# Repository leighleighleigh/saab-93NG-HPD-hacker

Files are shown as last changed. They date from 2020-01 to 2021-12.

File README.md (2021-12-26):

# saab-93NG-HPD-hacker
A reverse-engineering and interfacing board for the Saab Information Display / High Position Display, on 2003-2006 9-3 (Second Generation) Models.

<p align="center">
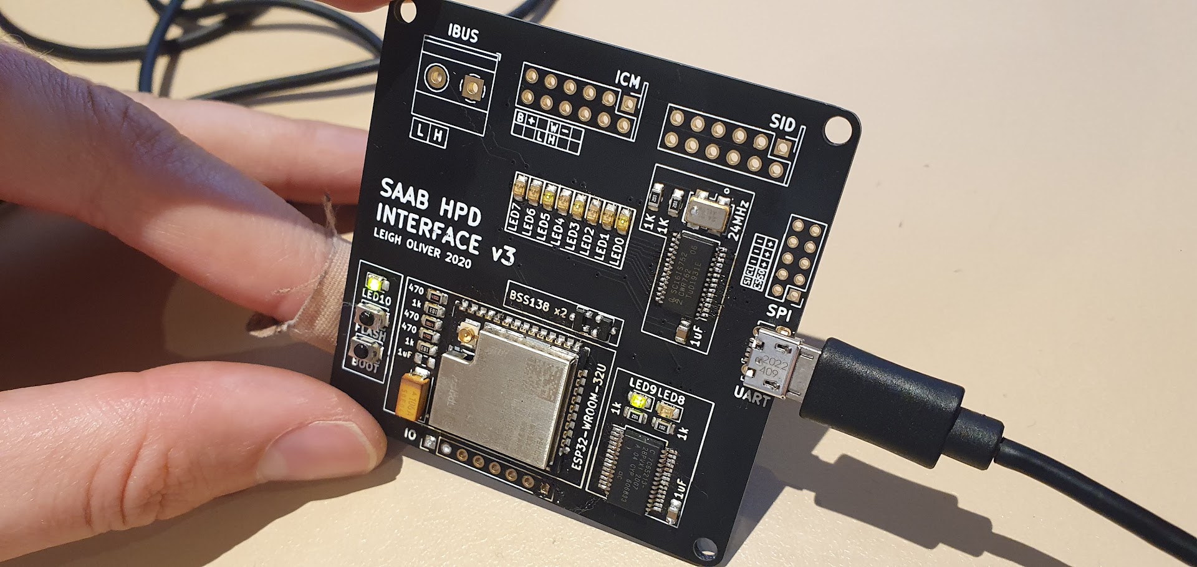
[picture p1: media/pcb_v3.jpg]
A square black circuit board with white text marked 'SAAB HPD INTERFACE v3' rests on a cream coloured benchtop.

</p>

## Project Status (DEC **2021**)
The **third** prototype of the PCB has been assembled and tested, as of August **2020**.
During this testing period, mild success was had, and some text/images were displayed. The full protocol is yet to be determined.
<p align="center">
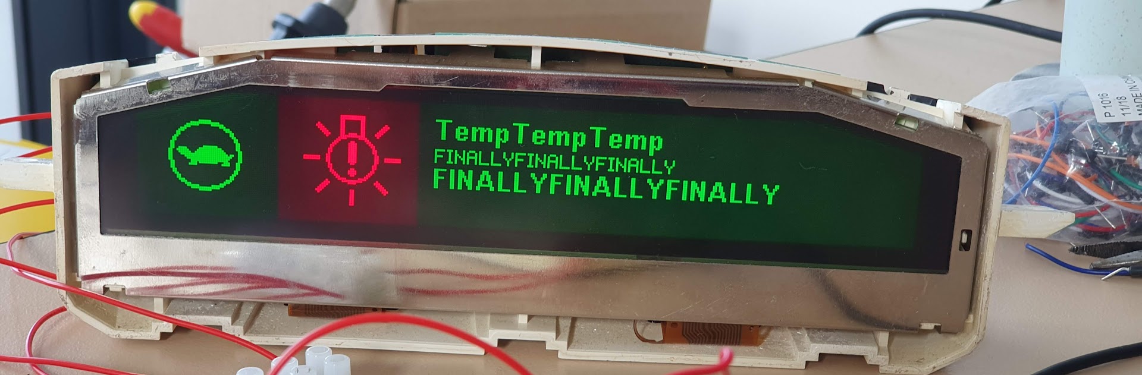
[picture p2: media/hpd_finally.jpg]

</p>

## Protocol Reverse Engineering
Please see [UART PROTOCOL](/UART_PROTOCOL.md) 

## Hardware Diagram
### Full In-car System
<p align="center">
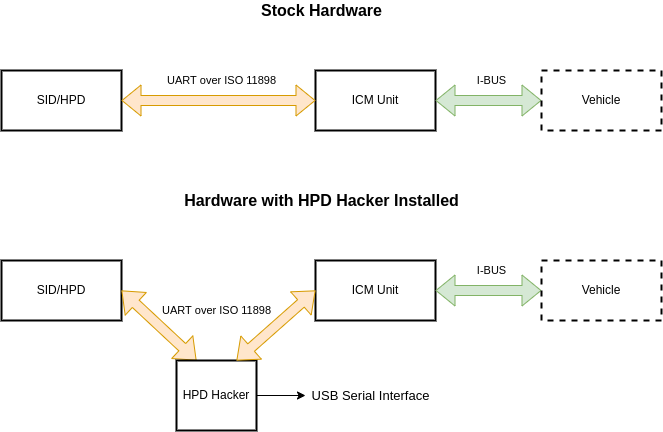
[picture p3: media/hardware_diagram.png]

</p>

### HPD Interface v3 Internals (WIP)
The HPD hacker is unusual in that it utilises a dedicated UART interface accesible over SPI.
This eliminates the need for dedicated UART interfaces on the host microcontroller, which was a concern when the original design targeted the ESP8266.
The ESP32 series has enough hardware UARTs to do this on it's own, which will be utilised in the next hardware revision.
<p align="center">
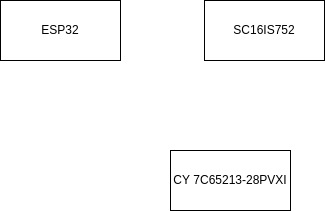
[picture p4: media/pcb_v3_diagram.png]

</p>

## Project structure
```bash
├── data_dumps # Raw UART data, CSV files exported from 'KingstVIS' software
├── hardware # KICAD v5+ projects
├── media # Images and diagrams
├── software # PlatformIO projects for the microcontrollers used here
└── PROTOCOL.md # This is where the results of our efforts is stored
```

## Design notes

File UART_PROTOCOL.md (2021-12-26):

# SID HPD Protocol
This document is incomplete.

Thanks to users **ruthenianboy** and **bojer** of trionictuning.com for their work in reverse-engineering the protocol of the SID.

## Physical Interface

- **115200baud** UART over CAN physical layer.

## Communication sequence

1. ICM sends command to SID
2. SID replies with ACK/ERROR or other frame. 
3. SID ALWAYS replies.

## Frame format

| 0x4 | 0x70 | 0x0  | 0x2 | 0x0 | 0x0 |
| --- | --- | ---- | --- | --- | --- |
| DLC(1) | COMMAND(1) | 0x0  | DATA(DLC-2)[0] | DATA(DLC-2)[1] | CHECKSUM(1) |

CHECKSUM is the MSB of all the non-DLC bytes.

## Commands table

| COMMAND BYTE | DATA BYTES DESCRIPTIONS | RESPONSE | DESCRIPTION |
| --- | --- | --- | --- |
| 0x80 | b0: Green LED brightness<br />b1: Orange/RED LED brightness  | OK | Adjusts backlight. |
| 0x81 | | 0x82...  | Status? |
| 0x83 | | 0x84...  | Status? |
| 0x10 | [0]: Region ID<br/>[2:3]: Sub-region ID <br/>[4]: ??? Usually 0x0<br/><br />[5]: Font Style<br />[6]: Width<br/>[8]: X Position<br/>[10]: Y Position<br/>[11+]: Text data | OK | Setup layer on region, with text data. |
| 0x11 | [0]: Region ID<br/>[2:3]: Sub Region ID<br/>[4]: ????, 0x8 for normal, sometimes 0x2<br/>[5]: Style<br/> # 0x00, normal<br/> # 0x10, right aligned<br/> # 0x20, blinking<br/> # 0x40, inverted <br/> # 0x80, underline<br /> | OK | Adjust layer presentation. |
| 0x60 | [0]: Region ID<br />[2]: Clear Flag (0x0) | OK | CLEAR region. |
| 0x70 | [0]: Region ID<br />[2]: Draw Flag (0 or 1) | OK | DRAW region. |
| 0x30 | # [0]: Region ID<br/># [2:3]: Sub-region ID<br/># [4]: Icon Number<br/># [5]: Icon Style<br/># [6]: X Pos<br/># [7]: Right Align | | Setup ICON |
| 0x33 | usual region stuff. 4,5 are car door state. 6 is x pos like icon. 7 must be 0 else no works. | | Draw CAR door stats |
| 0x40 | | | Some kind of raw display stuff, does weird things. |
| 0xa0 | | | Not sure? |
| 0x20 | | | Related to creating groups of sub-regions. |
| 0x21 | | | Related to moving groups of sub-regions. |
| | | | |

- 0x80,0x80 clear screen / screen off
- 0x80,0x00,0xCE,0x00 (sets backlight for orange portion, last value is brightness)
      0xC, shows only the orange portion.

- 0x80,0x00-x79 screen on, brightess command?
- 0x81,0x00 (gets info from SID, status query?)
- 0x83,0x00 (gets some kind of info from SID, status query?)
- 0x11 < draw data to screen

- 0x70,0x0,0x76,0x0,0x01 < Displays brake light failure icon

- 0x94, some kind of serial code
- 0x96, some other kind of serial code

- 0x9f,0x00 < self test mode

Return values

- 0xff,0x00 (success)
- 0xfe,0x00,0x31 (invalid commmand / command doesn't exist)
- 0xfe,0x00,0x34 (invalid command length, arguments?)
- 0xfe,0x00,0x35 ( no idea)
- 0xfe,0x0,0x37 (no idea)

## MISC

- Panel resolution (green) is 384x64 px
- Icon resolution (orange) is 64x64 px
- Temp and light sensors
- 4 font sizes, underscore, solid background, flashing, and align right styles.

## ICON DATA CODES (DECIMAL):

- dec	desc		
- 65	!		
- 66	washer 	?	
- 67	wipers !		
- 68	CRUISE		
- 69	BREAK Park		
- 70	BREAK !		
- 71	BREAK ABS		
- 72	BATTERY		
- 73	COOLANT		
- 74	OIL temp		
- 75	OIL		
- 76	OIL level		
- 77	ENGINE		
- 78	CAR		
- 79	DOOR FL		
- 80	DOOR RL		
- 81	DOOR FR		
- 82	DOOR RR		
- 83	BOOT		
- 84	LIGHT		
- 85	AHL !		
- 86	GEARBOX !		
- 87	GEARBOX temp		
- 88	TURTLE	???	
- 89	SERVICE		
- 90	PASS		
- 91	SRS		
- 92	KEY		
- 93	KEY battery		
- 94	LOCK !		
- 95	CAR LOCK !		
- 96	SEATS rear		
- 97	"P"		
- 98	SPA on	???	
- 99	SPA off	???	
- 100	SPA !		
- 101	Tire !		
- 102	Tire dot		
- 103	STP		
- 104	SEATS front		
- 105	SCL lock		
- 106	SCL !		
- 107	ESP on		
- 108	ESP off		
- 109	STP closed	???	
- 110	STP !		
- 111	STP down	???	
- 112	SNOW/ACC off	???	
- 113	Fuel lid open	???	
- 114	NAV up		arrow
- 115	NAV up right		
- 116	NAV up left		
- 117	NAV UP		filled
- 118	NAV UP RIGHT		filled
- 119	NAV UP LEFT		filled
- 120	NAV HALF SKEW RIGHT		filled
- 121	NAV HALF SKEW LEFT		filled
- 122	NAV RIGHT		filled
- 123	NAV LEFT		filled
- 124	NAV RIGHT DOWN		filled
- 125	NAV LEFT DOWN		filled
- 126	NAV RETURN right		filled
- 127	NAV RETURN left		filled
- 128	NAV DOT		
- 129-135	NAV G right		arrow filled
- 136-142	NAV G left		arrow filled
- 143-156	NAV G background		
- 157	NAV TRIANGLE UP		filled
- 158	NAV UP target		filled
- 159	NAV WAYPOINT		filled
- 160	NAV up long		
- 161	NAV skew up right		
- 162	NAV right		
- 163	NAV skew down right		
- 164	NAV down		
- 165	NAV skew down left		
- 166	NAV left		
- 167	NAV skew up left		
- 168	NAV ROTATE LEFT		filled
- 169	NAV ROTATE RIGHT		filled

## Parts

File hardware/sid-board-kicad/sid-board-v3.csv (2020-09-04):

Source: | /home/leigh/Documents/GitHub/saab-sid-re-board/sid-board-kicad/sid-board-v3.sch
Date: | Wed 02 Sep 2020 19:56:52
Tool: | Eeschema 5.1.5+dfsg1-2build2
Generator: | /usr/share/kicad/plugins/bom_csv_grouped_by_value.py
Component Count: | 49
Individual Components:
Item | Qty | Reference(s) | Value | LibPart | Footprint | Datasheet
 |  | C1 | 1uF | Device:C_Small | Capacitor_SMD:C_0805_2012Metric_Pad1.15x1.40mm_HandSolder | ~
 |  | C2 | 1uF | Device:C_Small | Capacitor_SMD:C_0805_2012Metric_Pad1.15x1.40mm_HandSolder | ~
 |  | C3 | 1uF | Device:C_Small | Capacitor_SMD:C_0805_2012Metric_Pad1.15x1.40mm_HandSolder | ~
 |  | C4 | 1uF | Device:C_Small | Capacitor_SMD:C_0805_2012Metric_Pad1.15x1.40mm_HandSolder | ~
 |  | C5 | 1uF | Device:C_Small | Capacitor_SMD:C_0805_2012Metric_Pad1.15x1.40mm_HandSolder | ~
 |  | C6 | 1uF | Device:C_Small | Capacitor_SMD:C_0805_2012Metric_Pad1.15x1.40mm_HandSolder | ~
 |  | C7 | 10uF | Device:C_Small | Capacitor_Tantalum_SMD:CP_EIA-6032-20_AVX-F_Pad2.25x2.35mm_HandSolder | ~
 |  | C8 | 1uF | Device:C_Small | Capacitor_SMD:C_0805_2012Metric_Pad1.15x1.40mm_HandSolder | ~
 |  | C9 | 1uF | Device:C_Small | Capacitor_SMD:C_0805_2012Metric_Pad1.15x1.40mm_HandSolder | ~
 |  | D1 | LED7 | Device:LED | LED_SMD:LED_0805_2012Metric_Pad1.15x1.40mm_HandSolder | ~
 |  | D2 | LED6 | Device:LED | LED_SMD:LED_0805_2012Metric_Pad1.15x1.40mm_HandSolder | ~
 |  | D3 | LED5 | Device:LED | LED_SMD:LED_0805_2012Metric_Pad1.15x1.40mm_HandSolder | ~
 |  | D4 | LED4 | Device:LED | LED_SMD:LED_0805_2012Metric_Pad1.15x1.40mm_HandSolder | ~
 |  | D5 | LED3 | Device:LED | LED_SMD:LED_0805_2012Metric_Pad1.15x1.40mm_HandSolder | ~
 |  | D6 | LED2 | Device:LED | LED_SMD:LED_0805_2012Metric_Pad1.15x1.40mm_HandSolder | ~
 |  | D7 | LED1 | Device:LED | LED_SMD:LED_0805_2012Metric_Pad1.15x1.40mm_HandSolder | ~
 |  | D8 | LED0 | Device:LED | LED_SMD:LED_0805_2012Metric_Pad1.15x1.40mm_HandSolder | ~
 |  | D9 | LED_IO2 | Device:LED_Small | LED_SMD:LED_0805_2012Metric_Pad1.15x1.40mm_HandSolder | ~
 |  | D10 | 1N5819 | Diode:1N5819 | Diode_SMD:D_SOD-123 | http://www.vishay.com/docs/88525/1n5817.pdf
 |  | D11 | 1N5819 | Diode:1N5819 | Diode_SMD:D_SOD-123 | http://www.vishay.com/docs/88525/1n5817.pdf
 |  | D12 | LED0 | Device:LED | LED_SMD:LED_0805_2012Metric_Pad1.15x1.40mm_HandSolder | ~
 |  | D13 | LED0 | Device:LED | LED_SMD:LED_0805_2012Metric_Pad1.15x1.40mm_HandSolder | ~
 |  | I-BUS1 | Screw_Terminal_01x02 | Connector:Screw_Terminal_01x02 | TerminalBlock_Phoenix:TerminalBlock_Phoenix_MKDS-1,5-2-5.08_1x02_P5.08mm_Horizontal | ~
 |  | ICM1 | ICM_CONN | local_symbols:Conn_02x06_SAAB_SID_HPD | sid-board:SAAB_SID_CONNECTOR_HEADER | ~
 |  | J1 | SPI + UART | Connector_Generic:Conn_02x05_Counter_Clockwise | Connector_PinHeader_2.00mm:PinHeader_2x05_P2.00mm_Vertical | ~
 |  | J2 | USB_B_Micro | Connector:USB_B_Micro | Connector_USB:USB_Micro-B_Molex-105017-0001 | ~
 |  | J3 | Conn_01x08 | Connector_Generic:Conn_01x08 | Connector_PinHeader_2.54mm:PinHeader_1x08_P2.54mm_Vertical | ~
 |  | Q1 | BSS138 | Transistor_FET:BSS138 | Package_TO_SOT_SMD:SOT-23 | https://www.fairchildsemi.com/datasheets/BS/BSS138.pdf
 |  | Q2 | BSS138 | Transistor_FET:BSS138 | Package_TO_SOT_SMD:SOT-23 | https://www.fairchildsemi.com/datasheets/BS/BSS138.pdf
 |  | R1 | 1K | Device:R_Small | Resistor_SMD:R_0805_2012Metric_Pad1.15x1.40mm_HandSolder | ~
 |  | R2 | 470 | Device:R_Small | Resistor_SMD:R_0805_2012Metric_Pad1.15x1.40mm_HandSolder | ~
 |  | R3 | 470 | Device:R_Small | Resistor_SMD:R_0805_2012Metric_Pad1.15x1.40mm_HandSolder | ~
 |  | R4 | 10k | Device:R_Small | Resistor_SMD:R_0805_2012Metric_Pad1.15x1.40mm_HandSolder | ~
 |  | R5 | 10k | Device:R_Small | Resistor_SMD:R_0805_2012Metric_Pad1.15x1.40mm_HandSolder | ~
 |  | R6 | 470 | Device:R_Small | Resistor_SMD:R_0805_2012Metric_Pad1.15x1.40mm_HandSolder | ~
 |  | R7 | 1k | Device:R_Small | Resistor_SMD:R_0805_2012Metric_Pad1.15x1.40mm_HandSolder | ~
 |  | R8 | 1k | Device:R_Small | Resistor_SMD:R_0805_2012Metric_Pad1.15x1.40mm_HandSolder | ~
 |  | R18 | 1K | Device:R_Small | Resistor_SMD:R_0805_2012Metric_Pad1.15x1.40mm_HandSolder | ~
 |  | SID1 | SID_CONN | local_symbols:Conn_02x06_SAAB_SID_HPD | sid-board:SAAB_SID_CONNECTOR_HEADER | ~
 |  | SW1 | SW_EN | Switch:SW_Push | Button_Switch_SMD:SW_Push_SPST_NO_Alps_SKRK | ~
 |  | SW2 | SW_FLASH | Switch:SW_Push | Button_Switch_SMD:SW_Push_SPST_NO_Alps_SKRK | ~
 |  | U1 | SC16IS752IPW | local_symbols:SC16IS752IPW_SPI | Package_SO:TSSOP-28_4.4x9.7mm_P0.65mm | https://au.mouser.com/datasheet/2/302/SC16IS752_SC16IS762-1127856.pdf
 |  | U2 | MCP1703A-3302_SOT223 | Regulator_Linear:MCP1703A-3302_SOT223 | Package_TO_SOT_SMD:SOT-223-3_TabPin2 | http://ww1.microchip.com/downloads/en/DeviceDoc/20005122B.pdf
 |  | U3 | SN65HVD232 | Interface_CAN_LIN:SN65HVD232 | Package_SO:SOIC-8_3.9x4.9mm_P1.27mm | http://www.ti.com/lit/ds/symlink/sn65hvd230.pdf
 |  | U4 | SN65HVD232 | Interface_CAN_LIN:SN65HVD232 | Package_SO:SOIC-8_3.9x4.9mm_P1.27mm | http://www.ti.com/lit/ds/symlink/sn65hvd230.pdf
 |  | U5 | CY7C65213-28PVXI | Interface_USB:CY7C65213-28PVXI | Package_SO:SSOP-28_5.3x10.2mm_P0.65mm | http://www.cypress.com/file/139881/download
 |  | U6 | ESP32-WROOM-32U | RF_Module:ESP32-WROOM-32U | RF_Module:ESP32-WROOM-32U | https://www.espressif.com/sites/default/files/documentation/esp32-wroom-32d_esp32-wroom-32u_datasheet_en.pdf
 |  | U7 | SN65HVD232 | Interface_CAN_LIN:SN65HVD232 | Package_SO:SOIC-8_3.9x4.9mm_P1.27mm | http://www.ti.com/lit/ds/symlink/sn65hvd230.pdf
 |  | X1 | ASE-xxxMHz | Oscillator:ASE-xxxMHz | Oscillator:Oscillator_SMD_EuroQuartz_XO53-4Pin_5.0x3.2mm_HandSoldering | http://www.abracon.com/Oscillators/ASV.pdf
Collated Components:
Item | Qty | Reference(s) | Value | LibPart | Footprint | Datasheet
1 | 8 | C1, C2, C3, C4, C5, C6, C8, C9 | 1uF | Device:C_Small | Capacitor_SMD:C_0805_2012Metric_Pad1.15x1.40mm_HandSolder | ~
2 | 1 | C7 | 10uF | Device:C_Small | Capacitor_Tantalum_SMD:CP_EIA-6032-20_AVX-F_Pad2.25x2.35mm_HandSolder | ~
3 | 1 | D1 | LED7 | Device:LED | LED_SMD:LED_0805_2012Metric_Pad1.15x1.40mm_HandSolder | ~
4 | 1 | D2 | LED6 | Device:LED | LED_SMD:LED_0805_2012Metric_Pad1.15x1.40mm_HandSolder | ~
5 | 1 | D3 | LED5 | Device:LED | LED_SMD:LED_0805_2012Metric_Pad1.15x1.40mm_HandSolder | ~
6 | 1 | D4 | LED4 | Device:LED | LED_SMD:LED_0805_2012Metric_Pad1.15x1.40mm_HandSolder | ~
7 | 1 | D5 | LED3 | Device:LED | LED_SMD:LED_0805_2012Metric_Pad1.15x1.40mm_HandSolder | ~
8 | 1 | D6 | LED2 | Device:LED | LED_SMD:LED_0805_2012Metric_Pad1.15x1.40mm_HandSolder | ~
9 | 1 | D7 | LED1 | Device:LED | LED_SMD:LED_0805_2012Metric_Pad1.15x1.40mm_HandSolder | ~
10 | 3 | D8, D12, D13 | LED0 | Device:LED | LED_SMD:LED_0805_2012Metric_Pad1.15x1.40mm_HandSolder | ~
11 | 1 | D9 | LED_IO2 | Device:LED_Small | LED_SMD:LED_0805_2012Metric_Pad1.15x1.40mm_HandSolder | ~
12 | 2 | D10, D11 | 1N5819 | Diode:1N5819 | Diode_SMD:D_SOD-123 | http://www.vishay.com/docs/88525/1n5817.pdf
13 | 1 | I-BUS1 | Screw_Terminal_01x02 | Connector:Screw_Terminal_01x02 | TerminalBlock_Phoenix:TerminalBlock_Phoenix_MKDS-1,5-2-5.08_1x02_P5.08mm_Horizontal | ~
14 | 1 | ICM1 | ICM_CONN | local_symbols:Conn_02x06_SAAB_SID_HPD | sid-board:SAAB_SID_CONNECTOR_HEADER | ~
15 | 1 | J1 | SPI + UART | Connector_Generic:Conn_02x05_Counter_Clockwise | Connector_PinHeader_2.00mm:PinHeader_2x05_P2.00mm_Vertical | ~
16 | 1 | J2 | USB_B_Micro | Connector:USB_B_Micro | Connector_USB:USB_Micro-B_Molex-105017-0001 | ~
17 | 1 | J3 | Conn_01x08 | Connector_Generic:Conn_01x08 | Connector_PinHeader_2.54mm:PinHeader_1x08_P2.54mm_Vertical | ~
18 | 2 | Q1, Q2 | BSS138 | Transistor_FET:BSS138 | Package_TO_SOT_SMD:SOT-23 | https://www.fairchildsemi.com/datasheets/BS/BSS138.pdf
19 | 2 | R1, R18 | 1K | Device:R_Small | Resistor_SMD:R_0805_2012Metric_Pad1.15x1.40mm_HandSolder | ~
20 | 3 | R2, R3, R6 | 470 | Device:R_Small | Resistor_SMD:R_0805_2012Metric_Pad1.15x1.40mm_HandSolder | ~
21 | 2 | R4, R5 | 10k | Device:R_Small | Resistor_SMD:R_0805_2012Metric_Pad1.15x1.40mm_HandSolder | ~
22 | 2 | R7, R8 | 1k | Device:R_Small | Resistor_SMD:R_0805_2012Metric_Pad1.15x1.40mm_HandSolder | ~
23 | 1 | SID1 | SID_CONN | local_symbols:Conn_02x06_SAAB_SID_HPD | sid-board:SAAB_SID_CONNECTOR_HEADER | ~
24 | 1 | SW1 | SW_EN | Switch:SW_Push | Button_Switch_SMD:SW_Push_SPST_NO_Alps_SKRK | ~
25 | 1 | SW2 | SW_FLASH | Switch:SW_Push | Button_Switch_SMD:SW_Push_SPST_NO_Alps_SKRK | ~
26 | 1 | U1 | SC16IS752IPW | local_symbols:SC16IS752IPW_SPI | Package_SO:TSSOP-28_4.4x9.7mm_P0.65mm | https://au.mouser.com/datasheet/2/302/SC16IS752_SC16IS762-1127856.pdf
27 | 1 | U2 | MCP1703A-3302_SOT223 | Regulator_Linear:MCP1703A-3302_SOT223 | Package_TO_SOT_SMD:SOT-223-3_TabPin2 | http://ww1.microchip.com/downloads/en/DeviceDoc/20005122B.pdf
28 | 3 | U3, U4, U7 | SN65HVD232 | Interface_CAN_LIN:SN65HVD232 | Package_SO:SOIC-8_3.9x4.9mm_P1.27mm | http://www.ti.com/lit/ds/symlink/sn65hvd230.pdf
29 | 1 | U5 | CY7C65213-28PVXI | Interface_USB:CY7C65213-28PVXI | Package_SO:SSOP-28_5.3x10.2mm_P0.65mm | http://www.cypress.com/file/139881/download
30 | 1 | U6 | ESP32-WROOM-32U | RF_Module:ESP32-WROOM-32U | RF_Module:ESP32-WROOM-32U | https://www.espressif.com/sites/default/files/documentation/esp32-wroom-32d_esp32-wroom-32u_datasheet_en.pdf
31 | 1 | X1 | ASE-xxxMHz | Oscillator:ASE-xxxMHz | Oscillator:Oscillator_SMD_EuroQuartz_XO53-4Pin_5.0x3.2mm_HandSoldering | http://www.abracon.com/Oscillators/ASV.pdf

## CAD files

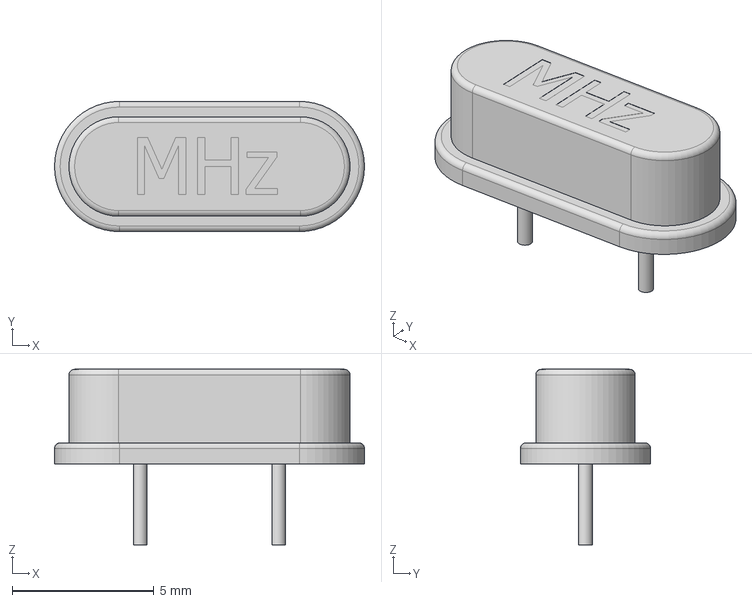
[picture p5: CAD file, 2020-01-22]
hardware/sid-board-kicad/local_libraries/3dmodels/Crystal Oscillator.stp
11.0 x 4.60 x 6.20 mm

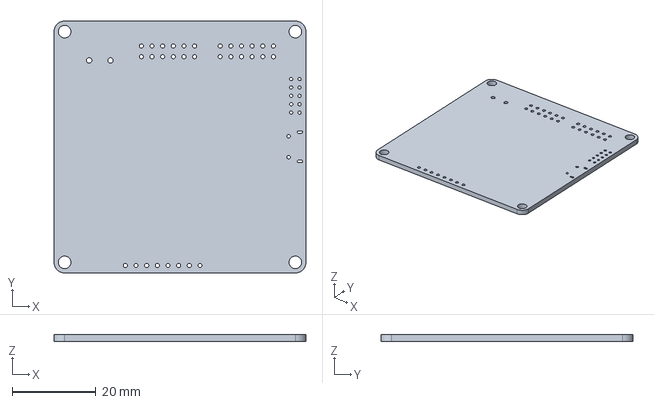
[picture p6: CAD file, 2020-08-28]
hardware/sid-board-kicad/sid-board-v3.step
60.1 x 60.1 x 1.60 mm

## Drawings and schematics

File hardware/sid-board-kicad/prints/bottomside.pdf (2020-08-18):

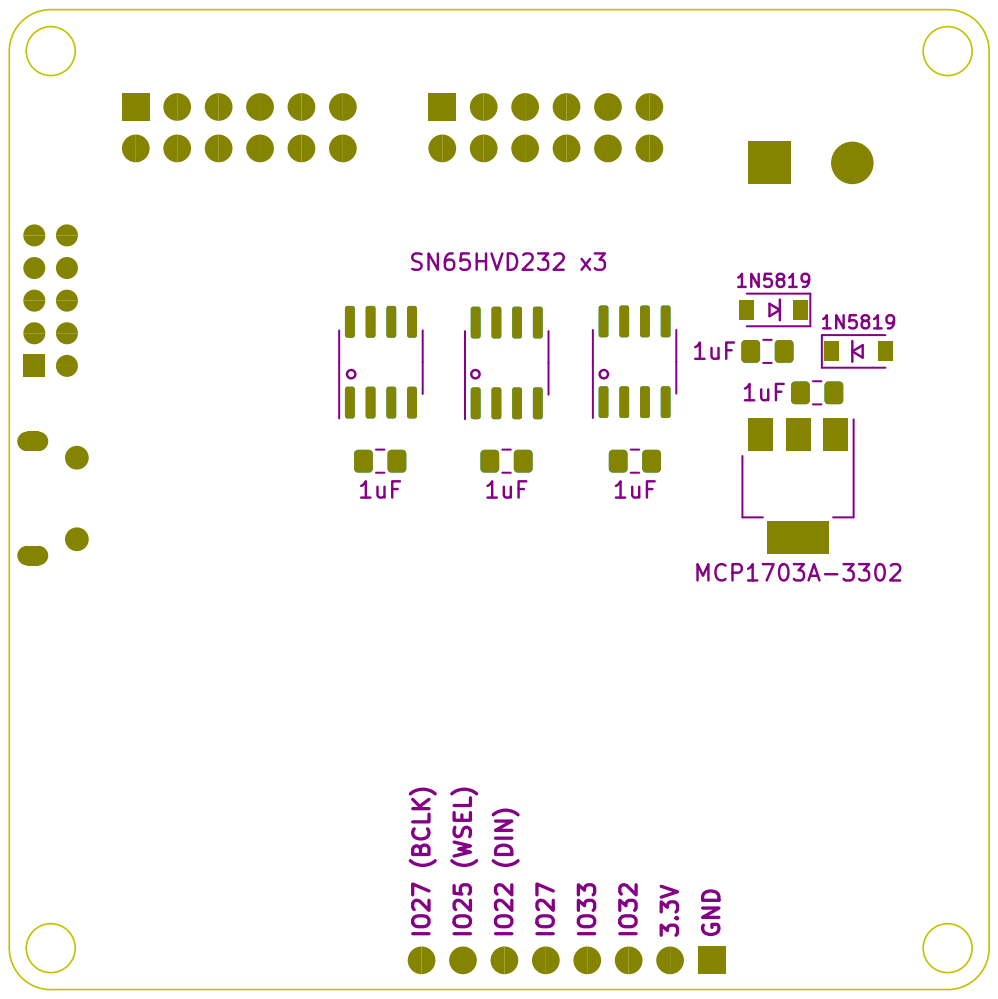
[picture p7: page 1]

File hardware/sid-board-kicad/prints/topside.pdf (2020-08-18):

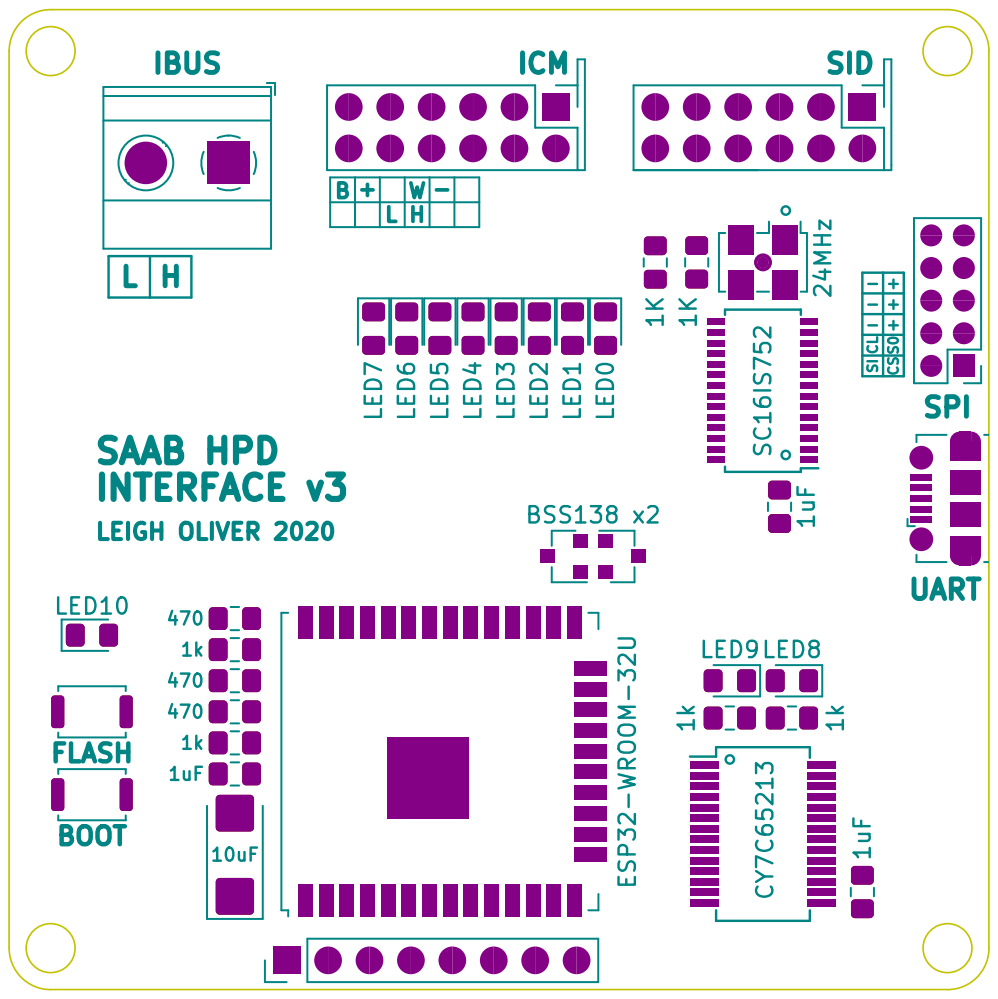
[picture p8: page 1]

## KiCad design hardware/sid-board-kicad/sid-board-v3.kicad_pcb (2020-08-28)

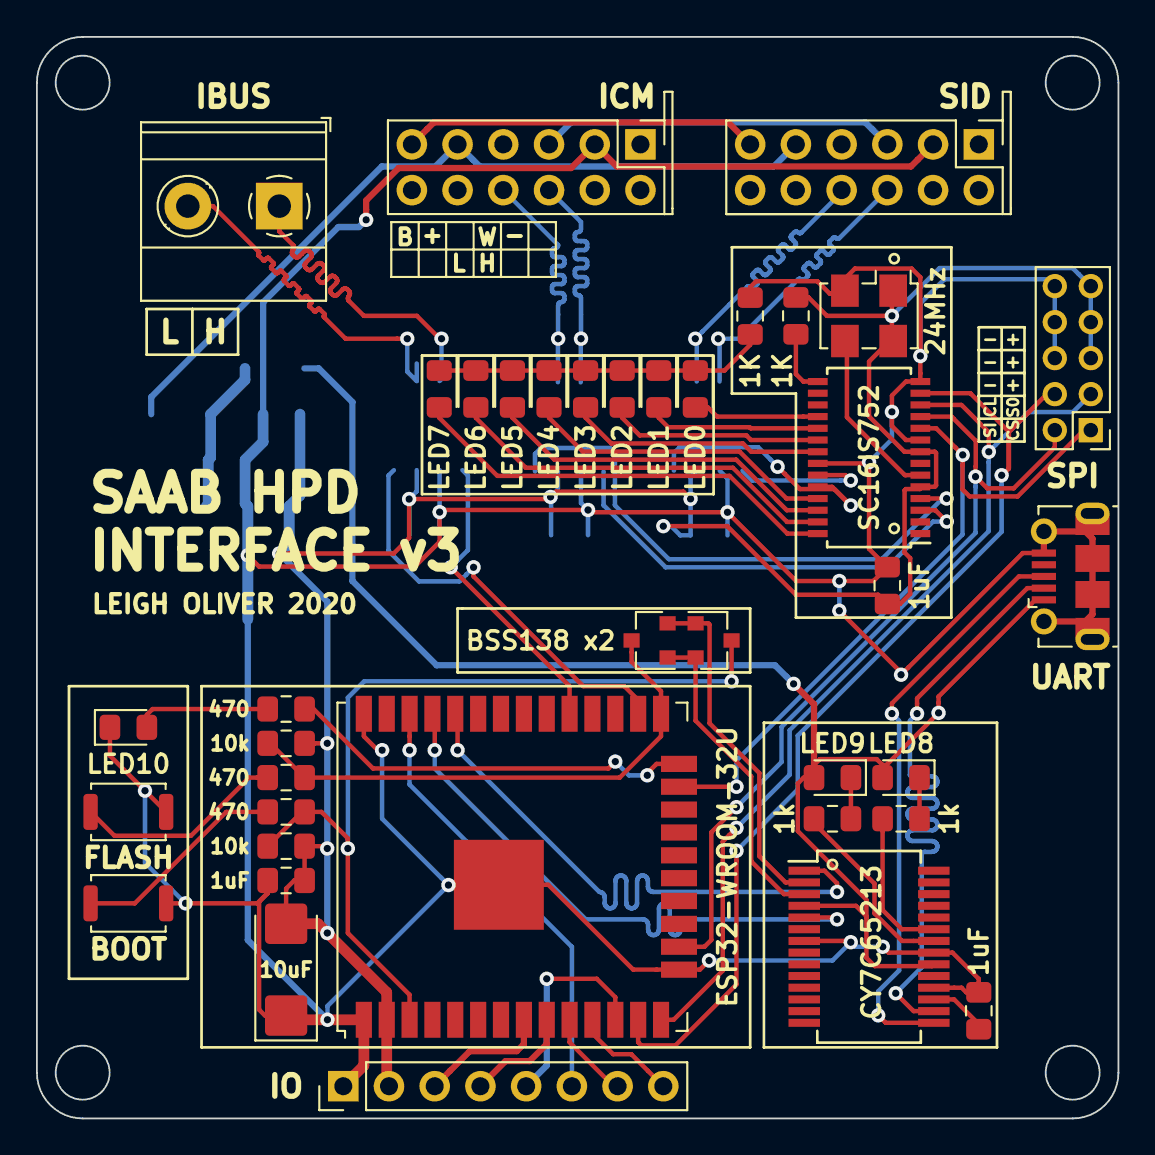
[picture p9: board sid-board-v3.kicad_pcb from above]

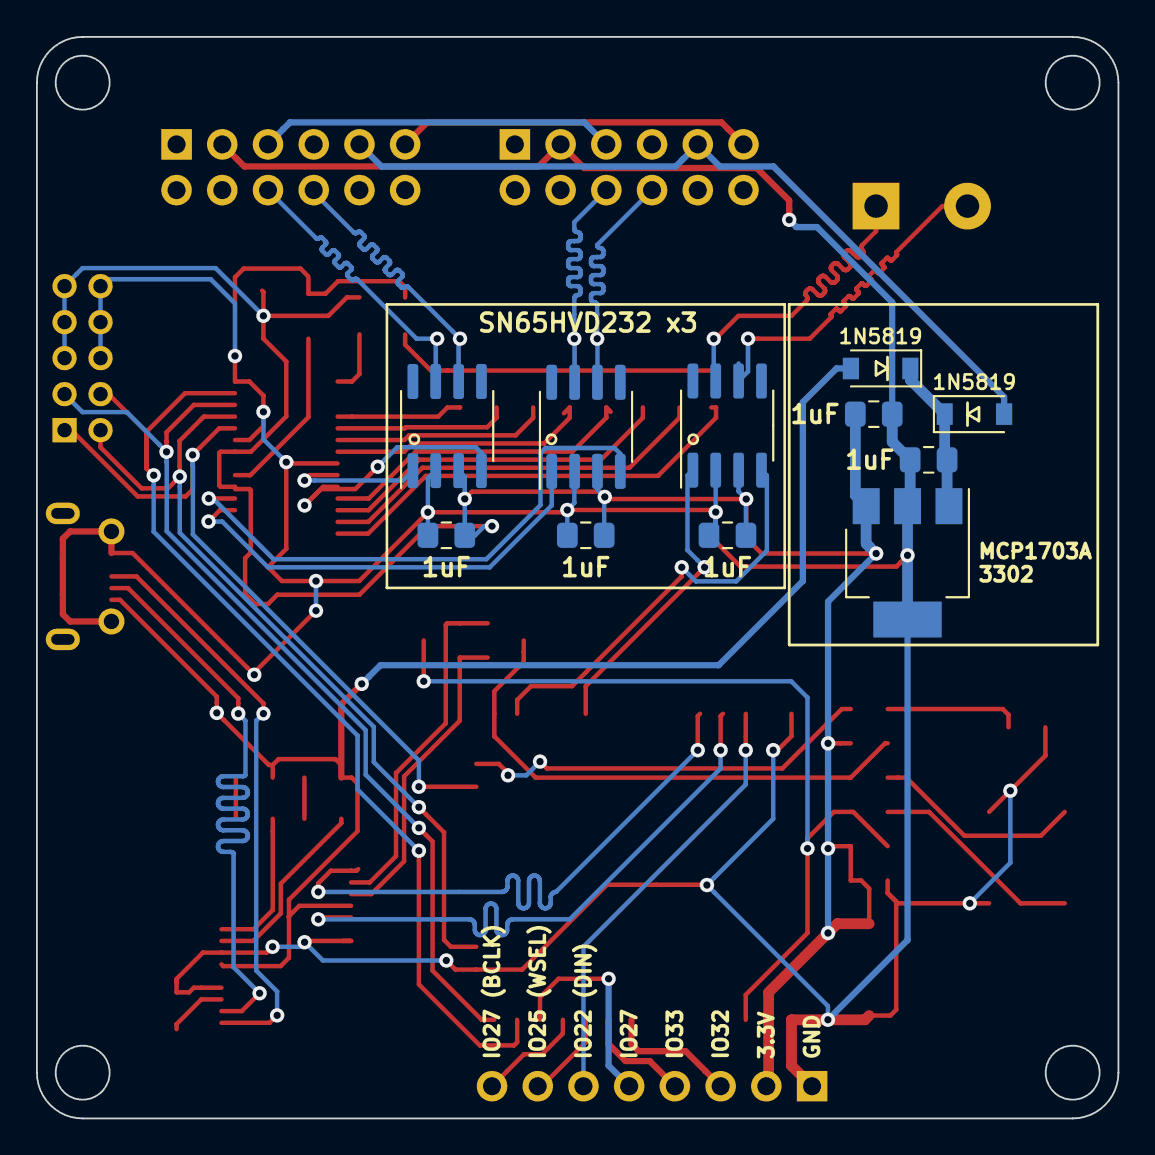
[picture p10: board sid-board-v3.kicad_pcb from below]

Board: 2 copper layers, 60.1 x 60.1 mm, 49 parts (11 on the bottom side), 57 nets.

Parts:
BSS138: BSS138 x2; SOT-23
C1, C2, C4, C5, C6, C8, C8#2, C9: 1uF; C_0805_2012Metric_Pad1.15x1.40mm_HandSolder
C7: 10uF; CP_EIA-6032-20_AVX-F_Pad2.25x2.35mm_HandSolder
D1: LED7; LED_0805_2012Metric_Pad1.15x1.40mm_HandSolder
D2: LED6; LED_0805_2012Metric_Pad1.15x1.40mm_HandSolder
D3: LED5; LED_0805_2012Metric_Pad1.15x1.40mm_HandSolder
D4: LED4; LED_0805_2012Metric_Pad1.15x1.40mm_HandSolder
D5: LED3; LED_0805_2012Metric_Pad1.15x1.40mm_HandSolder
D6: LED2; LED_0805_2012Metric_Pad1.15x1.40mm_HandSolder
D7: LED1; LED_0805_2012Metric_Pad1.15x1.40mm_HandSolder
D8: LED0; LED_0805_2012Metric_Pad1.15x1.40mm_HandSolder
D9: LED10; LED_0805_2012Metric_Pad1.15x1.40mm_HandSolder
D10, D11: 1N5819; D_SOD-123
D12: LED9; LED_0805_2012Metric_Pad1.15x1.40mm_HandSolder
D13: LED8; LED_0805_2012Metric_Pad1.15x1.40mm_HandSolder
I-BUS1: Screw_Terminal_01x02; TerminalBlock_Phoenix_MKDS-1,5-2-5.08_1x02_P5.08mm_Horizont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
ICM1: ICM_CONN; SAAB_SID_CONNECTOR_HEADER
J1: SPI; PinHeader_2x05_P2.00mm_Vertical
J2: UART; USB_Micro-B_Molex-105017-0001
J3: Conn_01x08; PinHeader_1x08_P2.54mm_Vertical
Q1: BSS138; SOT-23
R1, R18: 1K; R_0805_2012Metric_Pad1.15x1.40mm_HandSolder
R2, R3, R6: 470; R_0805_2012Metric_Pad1.15x1.40mm_HandSolder
R4, R5: 10k; R_0805_2012Metric_Pad1.15x1.40mm_HandSolder
R7, R8: 1k; R_0805_2012Metric_Pad1.15x1.40mm_HandSolder
SID1: SID_CONN; SAAB_SID_CONNECTOR_HEADER
SW1: BOOT; SW_Push_SPST_NO_Alps_SKRK
SW2: FLASH; SW_Push_SPST_NO_Alps_SKRK
U1: SC16IS752; TSSOP-28_4.4x9.7mm_P0.65mm
U2: MCP1703A3302; SOT-223-3_TabPin2
U3: SN65HVD232 x3; SOIC-8_3.9x4.9mm_P1.27mm
U4, U7: SN65HVD232; SOIC-8_3.9x4.9mm_P1.27mm
U5: CY7C65213; SSOP-28_5.3x10.2mm_P0.65mm
U6: ESP32-WROOM-32U
X1: 24MHz; Oscillator_SMD_EuroQuartz_XO53-4Pin_5.0x3.2mm_HandSoldering

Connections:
CAN_A_H: ICM1.10, U3.7
CAN_A_L: ICM1.9, U3.6
CAN_B_H: SID1.10, U4.7
CAN_B_L: SID1.9, U4.6
CAN_H: I-BUS1.1, U7.7
CAN_L: I-BUS1.2, U7.6
CLK: J1.4, U1.13, U6.13
CS: J1.1, U1.10, U6.23
DTR: BSS138.1, Q1.2, U5.2
EN: BSS138.3, R2.1, R4.2, U6.3
GND: C1.2, C2.2, C4.2, C5.2, C6.1, C7.1, C8.2, C8#2.2, C9.2, D9.1, ICM1.2, J1.6, J1.8, J1.10, J2.5, J2.6, J3.1, R18.2, SID1.2, SW1.1, SW2.1, U1.9, U1.14, U1.22, U2.2, U3.2, U4.2, U5.7, U5.18, U5.21, U6.1, U6.15, U6.38, U6.39, U7.2, X1.2
I2S_BCLK: J3.8, U6.11
I2S_DIN: J3.6, U6.36
I2S_WSEL: J3.7, U6.10
IO0: Q1.3, R3.1, R5.2, U6.25
IRQ: R1.1, U1.15
MISO: J1.3, U1.12, U6.14
MOSI: J1.2, U1.11, U6.16
unnamed: C4.1, U5.17
unnamed: D1.1, D2.1, D3.1, D4.1, D5.1, D6.1, D7.1, D8.1, R18.1
unnamed: D1.2, U1.28
unnamed: D2.2, U1.27
unnamed: D3.2, U1.26
unnamed: D4.2, U1.25
unnamed: D5.2, U1.21
unnamed: D6.2, U1.20
unnamed: D7.2, U1.19
unnamed: D8.2, U1.18
unnamed: D9.2, R6.1
unnamed: D11.2, ICM1.5, SID1.5
unnamed: D12.1, R7.2
unnamed: D13.1, R8.2
unnamed: ICM1.3, SID1.3
unnamed: ICM1.6, SID1.6
unnamed: J3.3, U6.8
unnamed: J3.4, U6.9
unnamed: J3.5, U6.12
unnamed: R2.2, SW1.2
unnamed: R3.2, SW2.2
unnamed: R6.2, U6.24
unnamed: R7.1, U5.22
unnamed: R8.1, U5.23
RTS: BSS138.2, Q1.1, U5.3
RXA: U1.4, U3.4
RXB: U1.24, U4.4
RX_ESP32: U5.1, U6.34
RX_ESP32_CAN: U6.26, U7.4
TXA: U1.3, U3.1
TXB: U1.23, U4.1
TX_ESP32: U5.5, U6.35
TX_ESP32_CAN: U6.29, U7.1
USB_DM: J2.2, U5.16
USB_DP: J2.3, U5.15
VBUS: D10.2, D12.2, D13.2, J2.1, U5.4, U5.20
VDD_3.3V: C1.1, C5.1, C6.2, C7.2, C8.1, C8#2.1, C9.1, J1.5, J1.7, J1.9, J3.2, R1.2, R4.1, R5.1, U1.5, U1.8, U2.3, U3.3, U4.3, U6.2, U7.3, X1.1, X1.4
VIN: C2.1, D10.1, D11.1, U2.1
XTAL1: U1.6, X1.3

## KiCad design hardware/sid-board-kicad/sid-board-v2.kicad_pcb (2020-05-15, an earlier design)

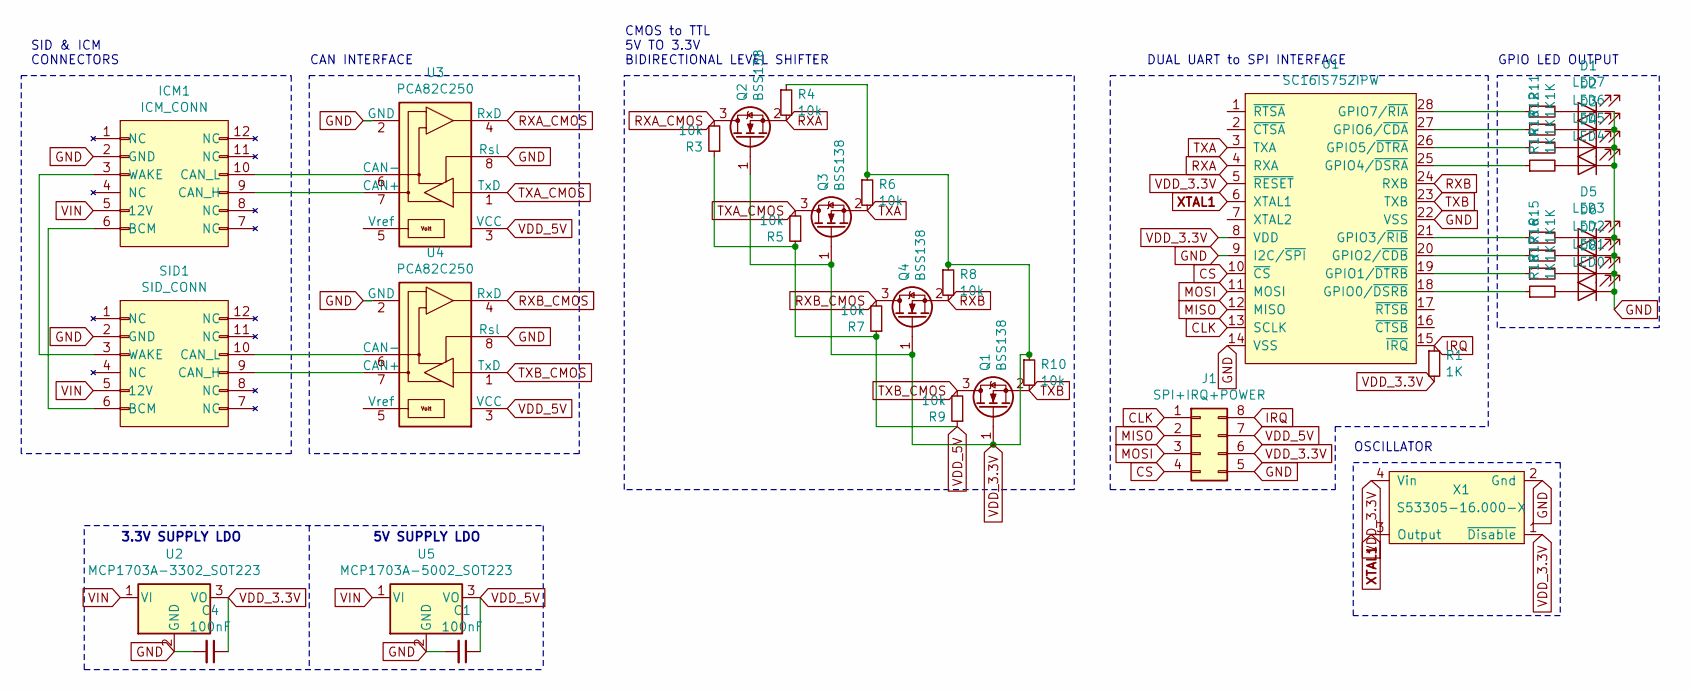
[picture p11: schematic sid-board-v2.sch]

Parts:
C1, C4: 100nF; C_0805_2012Metric_Pad1.15x1.40mm_HandSolder
D1: LED7; LED_0805_2012Metric_Pad1.15x1.40mm_HandSolder
D2: LED6; LED_0805_2012Metric_Pad1.15x1.40mm_HandSolder
D3: LED5; LED_0805_2012Metric_Pad1.15x1.40mm_HandSolder
D4: LED4; LED_0805_2012Metric_Pad1.15x1.40mm_HandSolder
D5: LED3; LED_0805_2012Metric_Pad1.15x1.40mm_HandSolder
D6: LED2; LED_0805_2012Metric_Pad1.15x1.40mm_HandSolder
D7: LED1; LED_0805_2012Metric_Pad1.15x1.40mm_HandSolder
D8: LED0; LED_0805_2012Metric_Pad1.15x1.40mm_HandSolder
ICM1: ICM_CONN; SAAB_SID_CONNECTOR_HEADER
J1: SPI+IRQ+POWER; PinSocket_2x04_P2.54mm_Vertical
Q1, Q2, Q3, Q4: BSS138; SOT-23
R1, R11, R12, R13, R14, R15, R16, R17, R18: 1K; R_0805_2012Metric_Pad1.15x1.40mm_HandSolder
R3, R4, R5, R6, R7, R8, R9, R10: 10k; R_0805_2012Metric_Pad1.15x1.40mm_HandSolder
SID1: SID_CONN; SAAB_SID_CONNECTOR_HEADER
U1: SC16IS752IPW; TSSOP-28_4.4x9.7mm_P0.65mm
U2: MCP1703A-3302_SOT223; SOT-223-3_TabPin2
U3, U4: PCA82C250; SOIC-8_3.9x4.9mm_P1.27mm
U5: MCP1703A-5002_SOT223; SOT-223-3_TabPin2
X1: S53305-16.000-X

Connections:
CLK: J1.1, U1.13 (SCLK)
CS: J1.4, U1.10 (~CS)
GND: C1.2, C4.2, D1.1 (K), D2.1 (K), D3.1 (K), D4.1 (K), D5.1 (K), D6.1 (K), D7.1 (K), D8.1 (K), ICM1.2 (GND), J1.5, SID1.2 (GND), U1.9 (I2C/~SPI), U1.14 (VSS), U1.22 (VSS), U2.2 (GND), U3.2 (GND), U3.8 (Rsl), U4.2 (GND), U4.8 (Rsl), U5.2 (GND), X1.2 (Gnd)
IRQ: J1.8, R1.1, U1.15 (~IRQ)
MISO: J1.2, U1.12 (MISO)
MOSI: J1.3, U1.11 (MOSI)
unnamed: D1.2 (A), R11.2
unnamed: D2.2 (A), R12.2
unnamed: D3.2 (A), R13.2
unnamed: D4.2 (A), R14.2
unnamed: D5.2 (A), R15.2
unnamed: D6.2 (A), R16.2
unnamed: D7.2 (A), R17.2
unnamed: D8.2 (A), R18.2
unnamed: ICM1.3 (WAKE), SID1.3 (WAKE)
unnamed: ICM1.6 (BCM), SID1.6 (BCM)
unnamed: ICM1.9 (CAN_H), U3.7 (CAN+)
unnamed: ICM1.10 (CAN_L), U3.6 (CAN-)
unnamed: R11.1, U1.28 (GPIO7/~RIA)
unnamed: R12.1, U1.27 (GPIO6/~CDA)
unnamed: R13.1, U1.26 (GPIO5/~DTRA)
unnamed: R14.1, U1.25 (GPIO4/~DSRA)
unnamed: R15.1, U1.21 (GPIO3/~RIB)
unnamed: R16.1, U1.20 (GPIO2/~CDB)
unnamed: R17.1, U1.19 (GPIO1/~DTRB)
unnamed: R18.1, U1.18 (GPIO0/~DSRB)
unnamed: SID1.9 (CAN_H), U4.7 (CAN+)
unnamed: SID1.10 (CAN_L), U4.6 (CAN-)
RXA: Q2.2 (S), R4.2, U1.4 (RXA)
RXA_CMOS: Q2.3 (D), R3.2, U3.4 (RxD)
RXB: Q4.2 (S), R8.2, U1.24 (RXB)
RXB_CMOS: Q4.3 (D), R7.2, U4.4 (RxD)
TXA: Q3.2 (S), R6.2, U1.3 (TXA)
TXA_CMOS: Q3.3 (D), R5.2, U3.1 (TxD)
TXB: Q1.2 (S), R10.2, U1.23 (TXB)
TXB_CMOS: Q1.3 (D), R9.2, U4.1 (TxD)
VDD_3.3V: C4.1, J1.6, Q1.1 (G), Q2.1 (G), Q3.1 (G), Q4.1 (G), R1.2, R4.1, R6.1, R8.1, R10.1, U1.5 (~RESET), U1.8 (VDD), U2.3 (VO), X1.1 (~Disable), X1.4 (Vin)
VDD_5V: C1.1, J1.7, R3.1, R5.1, R7.1, R9.1, U3.3 (VCC), U4.3 (VCC), U5.3 (VO)
VIN: ICM1.5 (12V), SID1.5 (12V), U2.1 (VI), U5.1 (VI)
XTAL1: U1.6 (XTAL1), X1.3 (Output)

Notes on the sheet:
3.3V SUPPLY LDO
5V SUPPLY LDO
SID & ICM CONNECTORS
CAN INTERFACE
DUAL UART to SPI INTERFACE
OSCILLATOR
CMOS to TTL 5V TO 3.3V BIDIRECTIONAL LEVEL SHIFTER
GPIO LED OUTPUT

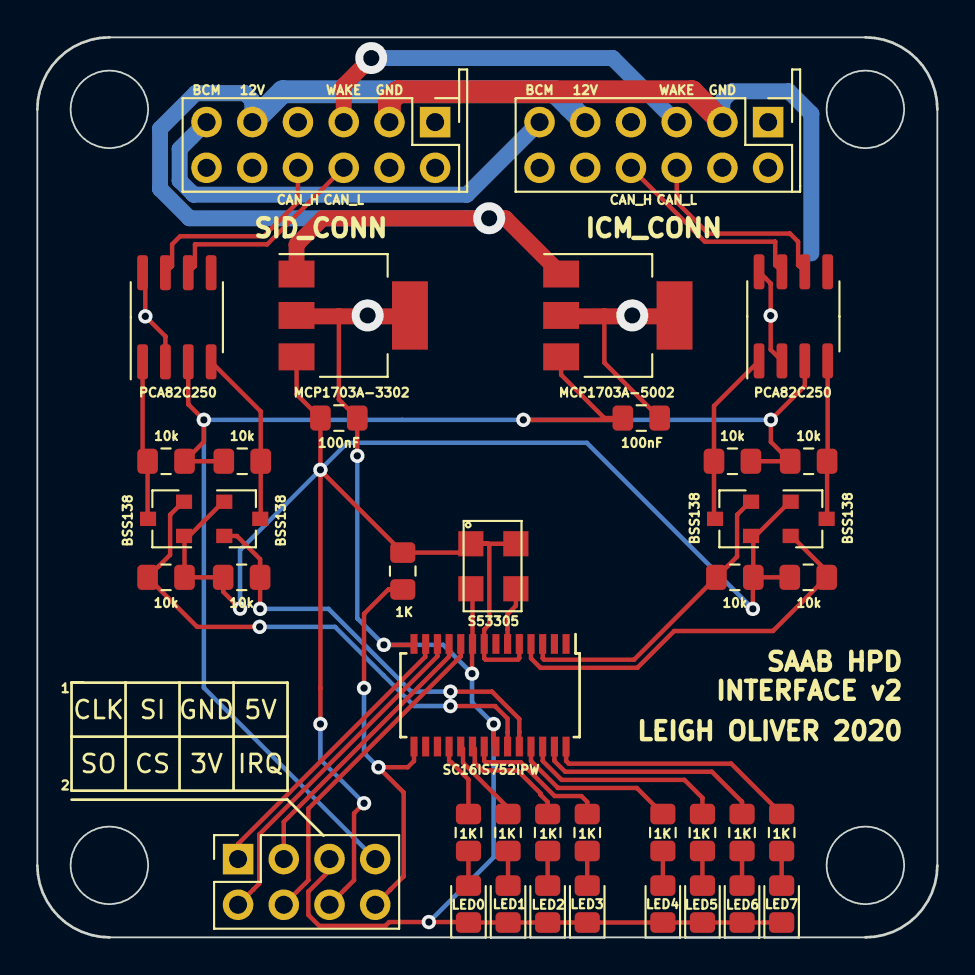
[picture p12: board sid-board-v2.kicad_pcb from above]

Board: 2 copper layers, 50.0 x 50.0 mm, 40 parts (0 on the bottom side), 40 nets.

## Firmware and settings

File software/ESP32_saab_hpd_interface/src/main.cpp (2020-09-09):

#include <Arduino.h>
#include <SPI.h>
#include <Wire.h>
#include <SC16IS752.h> // Dual UART interface
#include <string.h>
#include <stdio.h>
#include <sid_frame_utils.h>

#define SCK 14
#define MISO 12
#define MOSI 13
#define CS 15

SC16IS752 spiuart = SC16IS752(SC16IS750_PROTOCOL_SPI, CS);

#define baudrate_A 115200
#define baudrate_B 115200
int ignoreChannelBCount = 0;
int ignoreChannelACount = 0;

bool passThroughMode = true; // false, do serial to SID mode, //true, do in-car mode
bool fakeResponse = false; // Send OK reponse to everything haha.

int ledPin = 2;

//11,10,0,2,0,2,3,0,2,22,0,CF,0,1F,50,6C,61,79,D0
const char auxPlayMsg[] = {0x11,0x10,0x0,0x2,0x0,0x2,0x3,0x0,0x2,0x22,0x0,0xCF,0x0,0x1F,0x50,0x6C,0x61,0x79,0xD0};
int auxPlayMatchIndex = 0;
byte newPlayMsg[] = {0x10,0x0,0x2,0x0,0x2,0x3,0x0,0x2,0x22,0x0,0xD5,0x0,0x1F,0x42,0x54};
byte okMsg[] = {0xFF,0x00};

void setup()
{
  Serial.begin(921600);
  Serial.setTimeout(200);
  // Serial.println("Start UART -> SID adapter.");
  pinMode(ledPin,OUTPUT);
  digitalWrite(ledPin,1);


  // Setup SPI pins
  SPI.begin(SCK,MISO,MOSI,CS);
  SPI.setFrequency(4000000); // 4Mhz for the 752 uart ic

  // UART to Serial Bridge Initialization
  spiuart.begin(baudrate_A,baudrate_B); //baudrate setting
  
  if (spiuart.ping() != 1)
  {
    //Serial.println("Device not found");
    while (1)
      ;
  }

  // SETUP GPIO
  for(int gpioPin = 0; gpioPin < 8; gpioPin++){
    spiuart.pinMode(gpioPin, OUTPUT);
    spiuart.digitalWrite(gpioPin, LOW);
  }

  // Setup loopback
  spiuart.LoopbackEnable(false);
  
  spiuart.flush(SC16IS752_CHANNEL_A);
  spiuart.flush(SC16IS752_CHANNEL_B);
  Serial.flush();
}

void num2lights(int num)
{
  for(int gpioPin = 0; gpioPin < 8; gpioPin++){
    spiuart.digitalWrite(gpioPin, num & 1);
    num = num >> 1;
  }
}

void send_sid_data(byte channel,byte lenA,byte* data)
{
  uint16_t sum = 0;
  uint16_t len = lenA - 1;
  if(passThroughMode)
  {
    len = lenA;
  }

  if(channel == SC16IS752_CHANNEL_B){
    ignoreChannelBCount = len + 2;
  }
  if(channel == SC16IS752_CHANNEL_A){
    ignoreChannelACount = len + 2;
  }
  
  sum += len;

  spiuart.write(channel,len);  
  Serial.print("TX: 0x");
  
  Serial.print(len,HEX);
  Serial.print(",");

  for(byte i = 0; i<len; i++)
  {
    spiuart.write(channel,*data);
    Serial.print("0x");
    Serial.print(*data,HEX);
    Serial.print(",");
    sum += *data;
    data = data + sizeof(byte);
  }

  // Send the LSB of the sum.
  sum = sum & 0b11111111;
  spiuart.write(channel,sum);
  Serial.print("0x");
  Serial.println(sum,HEX);
}

String userInput;
uint8_t inputBuf[1024];

void parseUserInput(uint8_t * payload, size_t length)
{
  // Parse the input text payload as CSVs
  // Send this onto the serial bus via send_sid_data.
  char str[512];

  // Load payload into str (the buffer)
  memcpy(str,payload,length);

  const char s[2] = ",";

  uint16_t tokenIndex = 0;
  byte tokenData[512];
  char *token;
  
  /* get the first token */
  token = strtok(str, s);

  /* walk through other tokens */
  while( token != NULL ) {
    // Only do if token != '\n'
    // if(token != "\n" && token != "\0" && token != "\r"){
      // Parse token into array
      tokenData[tokenIndex++] = (byte)strtol(token, NULL, 0);
    // }

    // Get next token
    token = strtok(NULL, s);
  }

  // Send data using send_sid_data
  send_sid_data(SC16IS752_CHANNEL_B,tokenIndex,tokenData);
}

// int n = 0;

// Timeout for receiveing a valid RX frame

// SID RX buffer
byte rxBuffer[512];
uint16_t rxBufferIndex = 0;

void loop()
{
  if(!passThroughMode){
    // n++;
    // num2lights(n);

    if(spiuart.available(SC16IS752_CHANNEL_B) > 0){
      while (spiuart.available(SC16IS752_CHANNEL_B) > 0)
      {
        // read the incoming byte:
        char c = spiuart.read(SC16IS752_CHANNEL_B);
        if(ignoreChannelBCount == 0){
          // Fill up the RX buffer
          rxBuffer[rxBufferIndex++] = c;
          // Set lights to be the data
          //num2lights(c);
        }else{
          ignoreChannelBCount --;
        }
      }

      // Print the contents of the RX buffer
      if(rxBufferIndex != 0)
      {
        Serial.print("RX: ");
      }
      for(int i = 0; i<rxBufferIndex; i++)
      {
        Serial.print("0x");
        Serial.print(rxBuffer[i],HEX);
        Serial.print(",");
      }
      Serial.println("");

      // Reset RX buffer
      rxBufferIndex = 0;
    }

    
    // Check if we have stuff to read in serial
    if(Serial.available() > 0 and ignoreChannelBCount==0)
    {
      userInput = Serial.readStringUntil('\n');
      userInput.getBytes(inputBuf,512);
      parseUserInput(inputBuf,userInput.length());
      // Reset the rx buffer
      rxBufferIndex = 0;
    }
      
  }else{

    // If user input
    if(Serial.available() > 0)
    {
      char c  = Serial.read();
      // If SEND OKAY
      if(fakeResponse)
      {
        send_sid_data(SC16IS752_CHANNEL_A,2,okMsg);
      }
    }

    // Read from channel A and send to channel B
    if(spiuart.available(SC16IS752_CHANNEL_B) >= 3){
      Serial.print("SID:");
      while (spiuart.available(SC16IS752_CHANNEL_B) > 0)
      {
        // read the incoming byte:
        char c = spiuart.read(SC16IS752_CHANNEL_B);
        if(ignoreChannelBCount == 0){
          spiuart.write(SC16IS752_CHANNEL_A,c);
          ignoreChannelACount++;
          Serial.print(c,HEX);
          Serial.print(",");
        }else{
          ignoreChannelBCount --;
        }
      }
      Serial.println(";");
    }
    // Read from channel B and send to channel A
    if(spiuart.available(SC16IS752_CHANNEL_A) >= 3){
      Serial.print("ICM:");
      while (spiuart.available(SC16IS752_CHANNEL_A) > 0)
      {
        // read the incoming byte:
        char d = spiuart.read(SC16IS752_CHANNEL_A);
        if(ignoreChannelACount == 0){
          spiuart.write(SC16IS752_CHANNEL_B,d);
          ignoreChannelBCount++;
          Serial.print(d,HEX);
          Serial.print(",");

          // Check for match with the aux 'play' msg
          if(d == auxPlayMsg[auxPlayMatchIndex]){
            // If we are done matching
            if(auxPlayMatchIndex == 18){
              // Matched the last char, send replacement message
              Serial.println("Sending replacement bluetooth text");
              send_sid_data(SC16IS752_CHANNEL_B,17,newPlayMsg);
              // Reset aux play match
              auxPlayMatchIndex = 0;
            }else{
              auxPlayMatchIndex++;
            }
          }else{
            auxPlayMatchIndex = 0;
          }

        }else{
          ignoreChannelACount --;
        }
      }
      Serial.println(";");
    }
  }
}

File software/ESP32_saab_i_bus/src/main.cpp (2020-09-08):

#include <Arduino.h>
#include <string.h>
#include <stdio.h>
#include <ESP32CAN.h>
#include <CAN_config.h>

int ledPin = 2;
bool ledPinState = false;

CAN_device_t CAN_cfg;               // CAN Config
const int rx_queue_size = 10;       // Receive Queue size
unsigned long previousMillis = 0;   // will store last time a CAN Message was send
const int interval = 1000;          // interval at which send CAN Messages (milliseconds)


void setup()
{
  delay(1000);
  Serial.begin(115200);
  Serial.println("I-BUS INTERFACE");

  pinMode(ledPin,OUTPUT);
  digitalWrite(ledPin,1);

  // Setup can interface
  CAN_cfg.speed = CAN_SPEED_125KBPS;
  CAN_cfg.tx_pin_id = GPIO_NUM_5;
  CAN_cfg.rx_pin_id = GPIO_NUM_4;
  CAN_cfg.rx_queue = xQueueCreate(rx_queue_size, sizeof(CAN_frame_t));
  // Init CAN Module
  ESP32Can.CANInit();
}

void loop()
{

  unsigned long currentMillis = millis();
  
  // Send CAN Message
  if (currentMillis - previousMillis >= interval) {
    Serial.println("TX!");
    digitalWrite(ledPin,ledPinState);
    ledPinState = !ledPinState;
    previousMillis = currentMillis;
    CAN_frame_t tx_frame;
    tx_frame.FIR.B.FF = CAN_frame_std;
    tx_frame.MsgID = 0x001;
    tx_frame.FIR.B.DLC = 8;
    tx_frame.data.u8[0] = 0x00;
    tx_frame.data.u8[1] = 0x01;
    tx_frame.data.u8[2] = 0x02;
    tx_frame.data.u8[3] = 0x03;
    tx_frame.data.u8[4] = 0x04;
    tx_frame.data.u8[5] = 0x05;
    tx_frame.data.u8[6] = 0x06;
    tx_frame.data.u8[7] = 0x07;
    ESP32Can.CANWriteFrame(&tx_frame);
  }

  // Receive frame
  CAN_frame_t rx_frame;

  // Receive next CAN frame from queue
  if (xQueueReceive(CAN_cfg.rx_queue, &rx_frame, 3 * portTICK_PERIOD_MS) == pdTRUE) {

    if (rx_frame.FIR.B.FF == CAN_frame_std) {
      Serial.print("New standard frame");
    }
    else {
      Serial.print("New extended frame");
    }

    if (rx_frame.FIR.B.RTR == CAN_RTR) {
      Serial.printf(" RTR from 0x%08X, DLC %d\r\n", rx_frame.MsgID,  rx_frame.FIR.B.DLC);
    }
    else {
      Serial.printf(" from 0x%08X, DLC %d, Data ", rx_frame.MsgID,  rx_frame.FIR.B.DLC);
      for (int i = 0; i < rx_frame.FIR.B.DLC; i++) {
        Serial.printf("0x%02X ", rx_frame.data.u8[i]);
      }
      Serial.println("");
    }
  }
}

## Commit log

2020-01-15 Added initial board layout, still working on it. Need to make silkscreen.
    [sid-board.kicad_pcb, sid-board.sch]
2020-01-15 Happy with first prototype, going to try get it made!
    [sid-board-B_Cu.gbr, sid-board-B_Mask.gbr, sid-board-B_SilkS.gbr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]
2020-01-21 Removed unnessecary cap, re-arranged.
    [sid-board.kicad_pcb, sid-board.sch]
2020-01-22 Working on new mostly-SMD version, switched to independant LDOs, added oscillator circuit.
    [sid-board.kicad_pcb, sid-board.sch, sid-board_ldo_supplies.kicad_pcb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]
2020-01-22 Re-did PCB layout, signifcantly smaller now.
    [sid-board_ldo_supplies.kicad_pcb, sid-board_ldo_supplies.sch]
2020-01-22 Layout and edgecut tweaks.
    [sid-board_ldo_supplies.kicad_pcb]
2020-01-22 Added 3d files for proper female sockets, havn't placed yet. Added text.
    [1355505-1.stl, sid-board_ldo_supplies.kicad_pcb]
2020-01-22 Autorouted with Freerouting
    [sid-board_ldo_supplies.dsn, sid-board_ldo_supplies.kicad_pcb]
2020-01-22 Updated manually routed board, removed debugging UART header.
    [1355505-1.stl, Crystal Oscillator.stp, sid-board_ldo_supplies_autorouted.kicad_pcb]
2020-01-22 Autorouted vs Manual routed. Thinking about adding DIP switch.
    [sid-board_ldo_supplies.dsn, sid-board_ldo_supplies.kicad_pcb, sid-board_ldo_supplies.sch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]
2020-01-22 Edited some labels
    [sid-board_ldo_supplies.kicad_pcb]
2020-01-22 Added bypass DIP switch
    [sid-board_ldo_supplies.kicad_pcb, sid-board_ldo_supplies.sch]
2020-01-22 Added TODO text about putting interrupt connection back.
    [sid-board_ldo_supplies.sch]
2020-01-26 FINAL BEFORE FABRICATION!
    [sid-board_ldo_supplies-B_Cu.gbr, sid-board_ldo_supplies-B_Mask.gbr, sid-board_ldo_supplies-B_SilkS.gbr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]
2020-01-26 Removed old plot files
    [sid-board-B_Cu.gbr, sid-board-B_Mask.gbr, sid-board-B_SilkS.gbr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]
2020-01-26 Removed old files
    [sid-board_ldo_supplies_autorouted.kicad_pcb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]
2020-01-26 Updated edge cuts
    [sid-board_ldo_supplies-B_Cu.gbr, sid-board_ldo_supplies-B_Mask.gbr, sid-board_ldo_supplies-B_SilkS.gbr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]
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2020-02-12 SID Board v2 in the making.
    [sid-board-v2.kicad_pcb, sid-board-v2.sch]
2020-02-12 Working on SIDBOARD2 layout
    [sid-board-v2.sch]
2020-02-12 Updated SPI layout and README.md
    [sid-board-v2.kicad_pcb, sid-board-v2.sch]
2020-02-13 Finished draft layout of sid-board v2
    [sid-board-v2.kicad_pcb]
2020-02-14 Working on routing of sidboard v2.
    [sid-board-v2.dsn, sid-board-v2.kicad_pcb, sid-board-v2.sch]
2020-02-15 Finished first draft PCB layout of SIDBOARD2
    [sid-board-v2.kicad_pcb]
2020-02-17 Working on passthrough still. Probably a power issue.
    [main.cpp]
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2020-02-26 Added beginnings of ICM,SID daughterboard module.
    [pca82c250_saab_sid_interface.sch]
2020-02-26 Added beginnings of CAN daughterboard
    [saab_sid_can_daughterboard.kicad_pcb, saab_sid_can_daughterboard.sch]
2020-02-27 Things are getting desperate. Tried a direct IO method, not working. Need to whip out oscilloscope.
    [main.cpp]
2020-02-27 Working on CAN daughterboard
    [saab_sid_can_daughterboard.kicad_pcb, saab_sid_can_daughterboard.sch]
2020-03-06 Removed old boards projects
    [pca82c250_saab_sid_interface.sch, sid-board.kicad_pcb, sid-board.sch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]
2020-03-08 Having buffer re-write issues. This makes a feedback loop. Need to brainstorm and debug this...
    [main.cpp]
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2020-03-15 Fixed Serial always listening issue
    [main.cpp]
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2020-03-24 Added new custom footprint for crystal oscillator module, replacing the old crystal module
    [sid-board-v2.sch]
2020-03-24 Replaced crystal with oscillator module on PCB
    [sid-board-v2.kicad_pcb, sid-board-v2.sch]
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2020-05-08 Removed old daughterboard concept
    [saab_sid_can_daughterboard.kicad_pcb, saab_sid_can_daughterboard.sch]
2020-05-15 Cleaned up v2 board for prototype production
    [sid-board-v2-B_Cu.gbr, sid-board-v2-B_Mask.gbr, sid-board-v2-B_Paste.gbr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]
2020-05-16 Project re-organisation.
    [Crystal Oscillator.stp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]
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2020-08-02 Added analysis script
    [2020-08-02_22-56-46.csv]
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2020-08-10 Working on V3 board
    [sid-board-v3.kicad_pcb, sid-board-v3.sch]
2020-08-10 Assigned basic footprints
    [sid-board-v3.kicad_pcb, sid-board-v3.sch]
2020-08-10 Added UART interface to the SID BOARD V3
    [sid-board-v3.kicad_pcb, sid-board-v3.sch]
2020-08-10 Initial grouped PCB layout
    [sid-board-v3.kicad_pcb, sid-board-v3.sch]
2020-08-10 Experimenting with PCB layouts
    [sid-board-v3.kicad_pcb, sid-board-v3.sch, sid-board-v3_small.dsn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]
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2020-08-11 Improved routing in new version
    [sid-board-v3_blocklayout.kicad_pcb]
2020-08-12 Redid routing more logically
    [sid-board-v3.sch, sid-board-v3_blocklayout.kicad_pcb, sid-board-v3_deeppcb.kicad_pcb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]
2020-08-12 Happy with routing, replaced oscillator, need to label.
    [sid-board-v3.sch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]
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2020-08-14 Added IO expansion for free pins on ESP32
    [sid-board-v3.sch, sid-board-v3_blocklayout.kicad_pcb, sid-board-v3_small.dsn]
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2020-08-16 Lost labelling. Moved debug header.
    [sid-board-v3-B_Cu.gbr, sid-board-v3-B_Mask.gbr, sid-board-v3-B_Paste.gbr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]
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2020-08-18 Checked bootstrapping pins. Checked RX TX pins.
    [sid-board-v3.kicad_pcb, sid-board-v3.sch]
2020-08-18 Prints for silkscreen design
    [sid-board-v3.kicad_pcb]
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2020-08-18 Organisation and added more details
    [sid-board-v3-B_Cu.gbr, sid-board-v3-B_Mask.gbr, sid-board-v3-B_Paste.gbr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]
2020-08-24 Playing with 4 layer ideas
    [sid-board-v4.kicad_pcb, sid-board-v4.sch]
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2020-08-28 First succesfull blink sketch
    [sid-board-v3.step, sid-board-v4.kicad_sch]
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2020-08-29 Attempting to replace messages on the fly
    [clean_log.py, main.cpp]
2020-09-04 I forgot what I was doing
    [sid-board-v3.csv]
2020-09-05 Fixed buffer size issue
    [main.cpp, send_to_serial.py]
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2020-09-11 Added USBC port which I know exists
    [sid-board-v4.kicad_pcb, sid-board-v4.sch]
2021-12-26 README updated to reflect progress since late 2020
    [2020-08-02_22-56-46.csv, Crystal Oscillator.stp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]
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
